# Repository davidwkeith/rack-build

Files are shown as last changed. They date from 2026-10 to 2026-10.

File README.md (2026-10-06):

# rack-build — 3D-printed 19" rack panels

Three parametric OpenSCAD panels for a home 19" rack. Source files are in
`scad/`; the printable STLs are attached to each
[release](https://github.com/davidwkeith/rack-build/releases) rather than
kept in the repo. Printers: 2x Prusa i3 MK3S (250x210 mm bed).

**Test-first, every panel:** print the piece with a snap-fit or clip mechanism
first (right half of the 1U, column 1 of the 2U, one keystone piece) and
dry-fit the hardware before committing to a full print run. Several
mechanisms here are first-pass designs validated by geometry checks, not by
an actual print — see the cautions under each section.

---

## Print settings (all three files)

- **Material:** PETG
- **Orientation:** every panel piece prints with its front plate face-down on
  the bed (the .scad files handle this rotation automatically — just slice
  the STL as exported, don't reorient it in the slicer)
- **Supports:** none, for any piece. Stops, bosses and rail ends rise at 45
  degrees from the wall they grow out of, and the only overhangs left in
  the exported STLs are short bridges (12mm inside the Hue push-rod pier,
  16mm under the Pi sled, a 48mm strip of floor over the PoE window) and
  the tops of horizontal screw holes and pegs. A slicer's automatic
  supports will still build towers under every one of those holes, so
  leave supports switched off. This comes from measuring the STLs, not
  from a finished print.
- **Layer height / infill:** no hard requirement from the design; 0.2mm /
  15-20% infill is a reasonable default. Parts with threads cut directly
  into the plastic (standoffs, bosses) will hold a self-tapping screw better
  with higher infill in that specific region if your slicer supports it.

## Installation

To print the panels as published, download the STLs from the latest
[release](https://github.com/davidwkeith/rack-build/releases); nothing needs
installing. To change the designs or export the STLs yourself, you need
[OpenSCAD](https://openscad.org) and this repository.

On macOS, install the OpenSCAD development snapshot with
[Homebrew](https://brew.sh) (the release workflow builds with the
`openscad/openscad:dev` image, so the snapshot is the version to match):

```sh
brew install --cask openscad@snapshot
```

The cask doesn't put `openscad` on your PATH, which `build.sh` expects. Link
it:

```sh
ln -s /Applications/OpenSCAD.app/Contents/MacOS/OpenSCAD /usr/local/bin/openscad
```

(use `/opt/homebrew/bin` instead of `/usr/local/bin` on Apple Silicon).

Then clone the repository:

```sh
git clone https://github.com/davidwkeith/rack-build.git
cd rack-build
```

## Building

STLs are only generated by release builds: pushing a `v*` tag runs
[the release workflow](.github/workflows/release.yml), which exports every
piece and attaches the STLs to a GitHub release. To export them yourself
into `stl/` (ignored by git; needs `openscad` on your PATH, see
[Installation](#installation)):

```sh
./build.sh release
```

The preview images in this README are committed. After changing a source
file, re-render them with:

```sh
./build.sh
```

---

## Hardware shopping list (consolidated)

| Qty | Item | Used for |
|---|---|---|
| 18x | M3 x 8mm socket-head cap screw | Panel joints: 3 (1U Hue/Pi) + 12 (2U audio) + 3 (keystone) |
| 18x | M3 hex nut | Panel joints (nut traps) |
| 12x | 1.75mm filament offcuts, ~10mm long | Joint alignment dowels: 2 + 8 + 2 |
| 8x | M2.5 self-tapping screw | Raspberry Pi 5 to sled standoffs (4 per sled); not needed where a HAT's own standoffs do the job |
| 2x | M3 self-tapping screw | PoE++ bracket standoffs |
| 4x | M3 x 6mm pan-head self-tapping screw | Kinter MA170 tab mounting (2 per amp; 6x with a third zone). The tabs are 2mm, so the longest safe screw is 7mm; 6mm is the standard size that fits |
| 12x | M6 cage nut + screw | Rack ears, 4 per panel (the 2U has 8 holes; 4 is enough) |

Every joint is two 6mm flanges with a 3mm head recess on one side and a
2.8mm nut trap on the other, so an 8mm bolt ends inside the nut. A 10mm
bolt works too; it stands 1mm proud of the flange, clear of every device.

---

## 1. 1U — Hue Bridge + PoE++ injector + 2x Raspberry Pi 5

<picture>
  <source media="(prefers-color-scheme: dark)" srcset="images/rack-1u-hue-pi-dark.png">
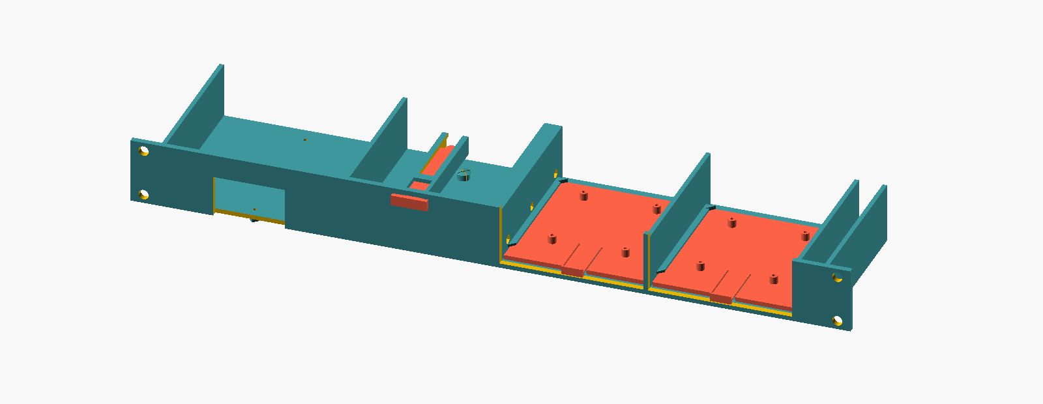
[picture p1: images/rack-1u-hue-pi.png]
1U shelf seen from the front: Hue bay with its push-rod on the left, two Raspberry Pi sleds on the right
  
</picture>

*Assembled, with the separately printed sleds, push-rod and pin in red.*

**Source:** `scad/rack-1u-hue-pi.scad`
**Pieces:** `rack-1u-left.stl`, `rack-1u-right.stl`, `rack-1u-sled.stl` (**print this one twice** — one per Pi), `rack-1u-pin.stl`, `rack-1u-rod.stl`

- **Left piece:** Philips Hue Bridge (model 3241312018) — front push-rod
  reaches the top sync button, two split snap-fit posts engage the Bridge's
  own keyhole + oval mounting slots. The UniFi PoE++ Adapter (60W) clips
  onto 2 printed standoffs on the floor's underside (92.80mm hole spacing,
  front-to-back) and hangs below the shelf; a 48x28mm front window keeps
  both port labels readable.
- **Right piece:** two Raspberry Pi 5 + PoE HAT sleds — one Home Assistant,
  one TBD. Each slides in from the front and latches via a flexing tongue
  riding a ratchet tooth, rather than lifting out from above (earthquake
  country — a Pi swap never needs the panel pulled from the rack). USB
  ports face front. The bays are sized for a Pi 5 under a
  [52Pi P30 PoE+ HAT](https://wiki.52pi.com/index.php?title=EP-0238), a
  ~30mm stack; that is tall enough that the bays are open at the top of the
  front plate rather than framed.

**Joint:** 3x M3 bolt + nut, 2x filament dowel, per half-to-half seam (one
seam total on this panel) = **3 bolts, 3 nuts, 2 dowels**.

**Assembly:**
1. Dry-fit one Pi sled into the right piece before printing a second — check
   the latch clicks in and lifting the pull lip releases it cleanly.
2. Bolt the two halves together while both are still empty: the bolt heads
   sit in the Hue bay and the nuts in the first Pi bay, and the Hue covers
   two of the three heads once it's in. Heads go in from the left piece's
   face, nuts tighten on the right piece's face. Seat the filament dowels
   first so the faces can't shift while you torque the bolts.
3. Push the Hue Bridge down into its left-piece pocket until the snap posts
   click; thread the push-rod and pin into the button-pusher channel from
   the front.
4. Screw the PoE++ adapter onto its 2 underside standoffs (M3 self-tap).
   **Check there's genuinely empty space in the rack slot directly below**
   — the adapter hangs ~31mm below the shelf floor.
5. Screw each Pi 5 onto its sled (4x M2.5 each, 8x total), USB/Ethernet
   toward the pull lip. If the HAT's standoffs have threaded studs, run
   those through the board into the sled's standoffs in place of the
   screws. Then slide both sleds into the right piece from the front until
   they latch. To pull one, lift the lip under the Pi's ports
   and draw the sled out by it.
6. Mount in the rack with M6 cage nuts.

**Open items** (all need the real hardware, not more modelling):
- **Needs calipers:** the Hue snap-post offsets are a photo estimate — if a
  post doesn't land in its slot, that's the first thing to re-check
  (`khole_dy` / `oval_dy`).
- **Needs a test fit:** the Pi + HAT height is 52Pi's published ~30mm, not
  a measurement. The model leaves it 2.7mm under the top of the 1U; set
  `pi_stack_h` if yours differs.
- **Needs a test print:** the Pi sled latch (flexing tongue + ratchet tooth)
  clears every interference check in the model but is untested as a
  physical mechanism. `ramp_h` in the .scad file is the knob to back off
  if the tooth grips too hard to release by hand.

---

## 2. 2U — Audio stacks (up to 3 AirPlay zones)

<picture>
  <source media="(prefers-color-scheme: dark)" srcset="images/rack-2u-audio-stacks-dark.png">
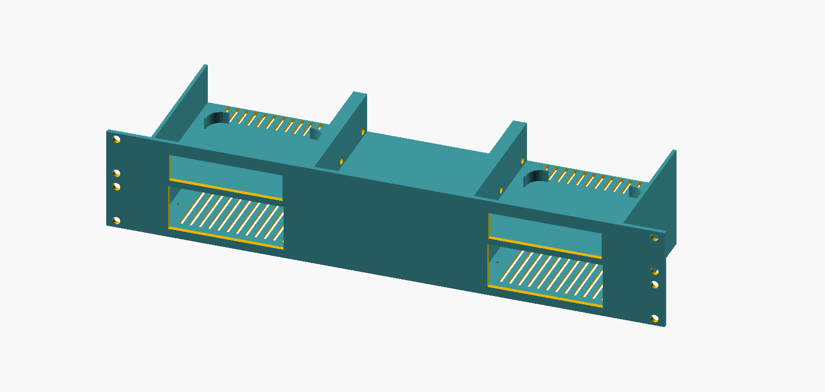
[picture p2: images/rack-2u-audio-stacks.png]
2U panel seen from the front: three bolted columns, the outer two with an AirPort window above an amp window
  
</picture>

**Source:** `scad/rack-2u-audio-stacks.scad`
**Pieces:** `audio-1.stl`, `audio-2.stl`, `audio-3.stl` (or `audio-2-stack.stl` in place of `audio-2.stl` for a third zone)

Three bolt-together columns. Each stack pairs one AirPort Express (upper U)
directly above one Kinter MA170 amp (lower U), one stack per AirPlay zone.

- **Columns 1 & 3 (zones 1 and 2):** AirPort front-flush (face against the plate, behind a full-face
  window for the status light) and two curved holders hugging its rear
  corners so it can't slide back; Kinter behind a 100 x 40mm window its knobs poke
  through (they stand 20mm proud of the front plate, for finger adjustment),
  with two printed screw bosses under the amp's factory mounting tabs.
  Front-to-back vent slots under the amp and in the upper floor behind the
  AirPort let its heat rise out of the stack. The amp
  floor sits 4mm up so those bosses stay inside the panel, and the AirPort
  floor sits 1mm above the amp rather than on the U line.
- **Column 2:** blank — the same floors and joints with no windows, holders
  or bosses. For a third zone, print `audio-2-stack.stl` as the middle
  piece instead: it is the same stack as columns 1 and 3 and bolts up
  identically.

**Joint:** 2 seams (col 1-2, col 2-3), each 6x M3 bolt + nut (3 Y-positions x
2 Z-levels, one level per U) + 4x filament dowel = **12 bolts, 12 nuts, 8
dowels** total across both seams.

**Assembly:**
1. Print column 1 first and dry-fit an amp and an AirPort in it before
   printing the rest.
2. Bolt the empty columns together in order (1-2, then 2-3), dowels first,
   same as the 1U panel. The bolt heads and nuts sit inside the bays, so
   this has to happen before the amps go in.
3. Slide each Kinter MA170 into its lower U from the rear until its face
   meets the front plate, and screw it to the floor bosses through the
   amp's factory tabs. The two driver holes in the upper floor sit straight
   above the tab screws: lower each screw through on the driver.
4. Slide each AirPort Express into its upper U from the rear until its face
   meets the front plate and the two curved rear holders cup its back corners. The driver holes stay clear either side of it, so
   an amp can come out without disturbing the AirPort.
5. Mount with M6 cage nuts — these columns carry protruding ear tabs that
   reach the rack's true 482.6mm width (the 3 columns' own content only
   spans 408mm).

**Open items:**
- **Tab screws:** the amp's tabs are 2mm, so the blind pilots (1mm skin
  under them) take a screw up to 7mm; M3 x 6mm gives about 4mm of grip.
- **Needs a test fit:** the amp bay is built from caliper measurements of
  one MA170 (103 x 70 x 43mm case, 124.5mm across the tabs, slots 113mm
  apart and 30-42mm behind the face) but hasn't been printed. Fit an amp
  to column 1 before printing the rest.

---

## 3. 1U — 24-port keystone patch panel

<picture>
  <source media="(prefers-color-scheme: dark)" srcset="images/rack-1u-keystone-panel-dark.png">
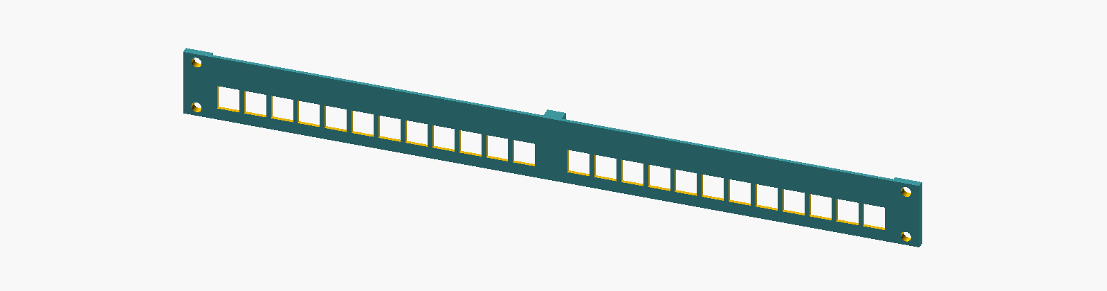
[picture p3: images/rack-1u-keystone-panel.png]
1U keystone panel seen from the front: two bolted halves with twelve square cutouts each
  
</picture>

**Source:** `scad/rack-1u-keystone-panel.scad`
**Pieces:** `keystone-left.stl`, `keystone-right.stl` (12 ports each)

Standard 14.5 x 16mm keystone cutouts, industry-standard across brands.
Panel's thinned to 2.5mm specifically so keystone clips can actually engage
(the rest of this rack's panels are 4mm — too thick for most keystone
jacks' spring clips to reach). Ports sit low in the panel, leaving ~20mm of
clear space above each one for a label.

**Joint:** 3x M3 bolt + nut, 2x filament dowel = **3 bolts, 3 nuts, 2
dowels**.

**Assembly:**
1. **Print one piece and test a single keystone jack before printing both**
   — clip tolerance varies enough by brand/model that this is worth
   confirming. If jacks won't seat, thin the panel further; if they're
   loose, that's likely fine (the clip still does the retaining).
2. Bolt the two pieces together same as the other panels (heads from the
   left piece, nuts on the right, dowels first).
3. Snap jacks in from the rear, terminated or not — they self-retain, no
   bracket needed behind the panel.
4. Mount with M6 cage nuts.

---

## Also in the rack

Two things in the rack aren't these panels:

- **Router:** the UCG Fiber and its power supply sit in the
  [UCG Fiber + PSU 19 inch modular rack mount](https://www.printables.com/model/1359874-ucg-fiber-psu-19-inch-modular-rack-mount)
  by [Maurício Pessoa](https://www.printables.com/@Mauker) on Printables,
  printed as published.
- **Switch:** a Ubiquiti EdgeSwitch 24 (ES-24-250W), a 1U unit that mounts
  on its own rack ears with no printed parts.

---

## Superseded / not included

- `rack-1u-kinter-amps.scad` — standalone single-amp panel, replaced by the
  2U audio stacks (each amp now pairs with its own AirPort Express instead).
- An earlier "keyhole" cable-management panel design was replaced entirely
  by the keystone panel above — no files from that version exist.

Both are left out of this collection since they're not part of the current
build.

---

## Credits

All geometry here is original, but two ideas came from other people's
models on Printables:

- The Hue button pusher follows RobinUit's "button pusher" (model 480200).
- The front-loading Pi sleds nod to JaredC01's "1U Rackmount Cluster"
  (model 285853).

The Hue snap-post spacing was cross-checked against vladimir.aubrecht's
remix (model 125408) of Luther2k's Hue rack mount.

## License

[ISC](LICENSE) © [David W. Keith](https://dwk.io)

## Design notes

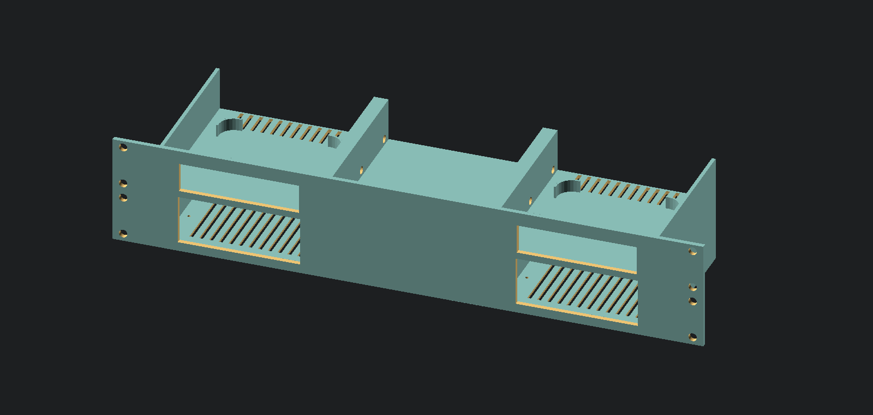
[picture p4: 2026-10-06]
images/rack-2u-audio-stacks-dark.png

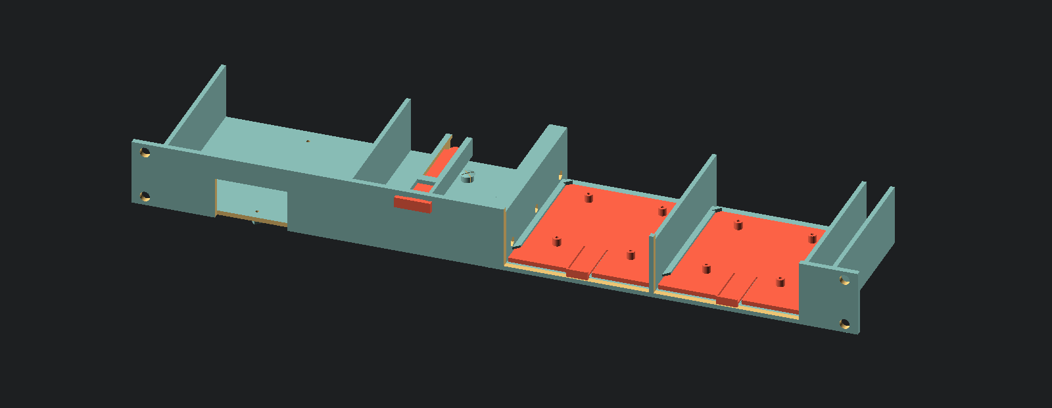
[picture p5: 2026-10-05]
images/rack-1u-hue-pi-dark.png

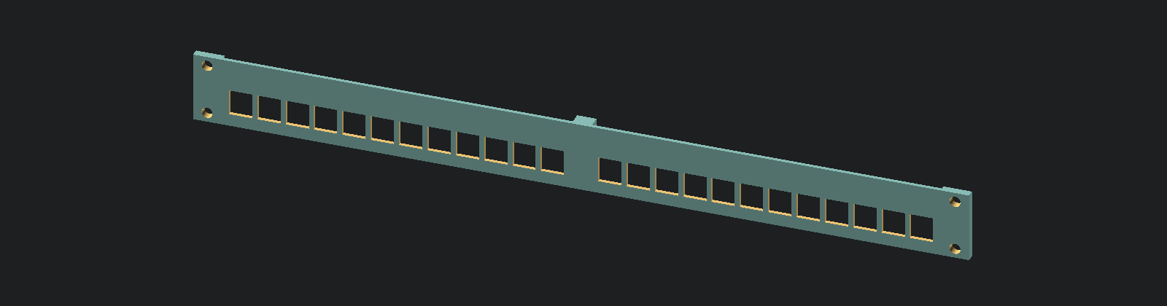
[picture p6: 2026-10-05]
images/rack-1u-keystone-panel-dark.png

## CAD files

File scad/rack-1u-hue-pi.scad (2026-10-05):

// 1U 19" rack mount, two halves bolted at the centre.
//   Left half : 1x Hue Bridge v2 + 1x Ubiquiti PoE++ Adapter (60W, U-POE++)
//   Right half: 2x Home Assistant Raspberry Pi 5 + PoE HAT, each on a removable sled (below)
// The Hue sits rear-flush (ports at the back) and gets a front push-rod button pusher (see its
// own section below) -- no LED light pipes, the unit's status LEDs are too dim to be worth
// routing. The PoE++ injector hangs from standoffs under the floor -- its Ethernet ports face
// the rack front through a window, AC cord exits to the rear.
// Print each half front-plate-down (print_orient = true), no supports. PETG, brim helps.
// Half is 241.3 mm wide; MK3S bed is 250 x 210.
// Model coordinates: X across, Y front(0)->rear, Z up. Floor bottom at Z=0.

/* [Part] */
part = "both"; // [both, assembly, left, right, pin, rod, sled]

/* [Rack (EIA-310)] */
rack_w      = 482.6;
ear_hole_x  = 465.1;   // hole centre-to-centre
ear_hole_dz = 31.75;   // 1U hole pair spacing
ear_hole_d  = 6.8;     // M6 cage-nut clearance
panel_h     = 43.66;   // 1U minus clearance
body_margin = 17.5;    // keep body inside the rails

/* [Shelf] */
plate_t     = 4;
floor_t     = 3;
wall_t      = 3;
wall_h      = 37;      // above floor -- tall enough to contain the PoE injector (34 mm) + a lip
flange_t    = 6;       // joint flange per half
shelf_depth = 116;     // includes plate_t -- deepened for the 106 mm-long PoE++ injector

/* [Devices: width(X) x depth(Y) x height(Z)] */
hue_dims = [91, 91, 26];     // Philips spec: ~90.6 x 90.9 x 26 mm
clr      = 1.0;              // total side clearance, all devices
hue_stop = 0.5;               // gap between Hue front and its stop wall
stop_wall_h = 25;             // front-registration rib height for Hue (capped by the room in
                               // front of it) -- stays low so it doesn't block the Hue pusher rod
hue_stop_dx = 28;             // the two stop ribs sit this far either side of the Hue's centre

/* [PoE++ mounting bracket (screws to the shelf UNDERSIDE; adapter clips onto the bracket's
   own sliders and hangs below the shelf -- it is no longer in a floor pocket) ] */
// Only 2 real screw holes -- the large countersunk pair, 92.80 mm apart centre-to-centre
// (direct caliper reading between the holes themselves, not a photo-scale estimate). The
// small holes next to the cleat aren't mounting points at all: they're part of how the
// adapter LATCHES onto the cleat, not how the bracket attaches to whatever it's screwed to.
// Hole diameter is still a photo estimate -- confirm before printing.
// Orientation: in normal use the bracket mounts to a WALL with Ethernet at the top, power
// cord at the bottom -- so the two holes sit along the Ethernet-to-power axis. That's the
// same axis as the adapter's own front(Ethernet)-to-rear(power) run through this rack, so
// the holes go along Y (front-to-back), not X, with the front one nearer the window above.
// CAUTION: the bracket is a thin plate, but the clipped-on adapter is ~31 mm thick in this
// orientation (measured; spec sheet says 34) and hangs straight down from the shelf floor --
// that will very likely intrude
// into whatever occupies the 1U slot directly below (e.g. the Kinter amp panel) unless a
// clear 1U gap is left there. Check real rack clearance before committing to this mount.
bracket_hole_dy = 46.4;    // half-spacing: 2 holes, 92.80 mm apart, same X (front/rear of bracket_cy)
bracket_cx = 162;          bracket_cy = shelf_depth / 2;   // centre of the hole pattern, in the
                                                             // left half's spare bay (local u)
                                                             // -- pick your own spot if this is wrong
bracket_pilot_d = 2.5;     // pilot hole for a self-tapping M3
bracket_boss_d  = 7;       bracket_boss_h = 4;   // printed standoff, hangs below the floor
// Connector end measured directly with calipers: 63.94 mm wide, ~31.2 mm tall (vs. 63 x 34 mm
// from Ubiquiti's spec sheet -- close on width, spec runs a bit tall, probably measured over a
// foot or lip calipers didn't catch). Widened from a plain cable slot to a real window so the
// two port labels (data / PoE++) printed above the jacks stay readable, not just cable access.
poe_pass_w = 48;  poe_pass_h = 28;  poe_pass_drop = 6;   // front window, open at the plate's
                                                           // bottom edge since the adapter hangs
                                                           // below rather than sitting in a pocket

/* [Home Assistant Pi sled -- front-slide, latching, swappable tray]
   Earthquake country, and the Pis are the part most likely to get swapped -- so the sled now
   slides in and out through the FRONT on a pair of rails, with a spring latch, instead of
   lifting out from above. A vertical lift would need clearance above this 1U that may not
   exist once the rack is populated; a front slide never requires pulling the panel. Concept
   nods to JaredC01's "1U Rackmount Cluster" (Printables 285853) but the mechanism is
   original -- theirs locks 5 sleds together with an all-thread rod through interlocking
   modules, built for a 5-bay PoE+OLED cluster; this is one bay with a simple channel + latch.
   UNTESTED PRINT-AND-FIT, like every other snap/latch in this file: dry-fit the rail
   clearance and latch spring force before committing to a full print. */
sled_dims = [95, 100, 3];        // W x D x plate thickness
sled_clr  = 1.5;                 // side clearance, bay vs sled
sled_corner = 6;                 // 45-degree cut on the sled's rear corners (see the rear stops)
sled_front_gap = 2;              // sled's front edge, FULLY INSERTED, to the plate's inner face
sled_overtravel = 1;             // how far past its latched position the sled can be pushed before
                                 // it meets the rear stop -- without this the catch bar has only
                                 // latch_clr to drop behind the tooth, less than print tolerance

/* [Pi sled rails + latch] */
rail_t = 1.6;      rail_depth = 4;     // retention lip: thickness, reach in from each side wall
rail_z0 = 0.3;                          // lip floats this far above the sled plate's top face
rail_start = 16;                        // lip begins this far back from the front opening, so
                                          // the sled's leading edge is already past the window
                                          // before the rails start gripping it
latch_w = 14;       latch_len = 30;     // cantilever tongue cut into the sled plate: width, length
latch_slit = 1;                         // slit width freeing the tongue to flex
latch_travel = 8;                       // rear edge of the tongue's catch bar, from the sled's
                                          // front edge. The bar is the only part of the sled left
                                          // full-thickness along the tooth's track -- the rest of
                                          // that track is relieved underneath (see pi_sled()) so
                                          // the sled can pass over the raised tooth at all
latch_catch = 3;                        // catch bar length; the tooth's sheer face lands just
                                          // in front of it once the sled is fully inserted
latch_clr = 0.3;                        // tooth-to-sled clearance, vertical and fore/aft
lip_ridge = [1.5, 2.5];                 // finger ridge at the pull lip's tip: thickness, height
ramp_len = 6;        ramp_h = 1.2;      // ratchet tooth: gentle rise over ramp_len, then an
                                          // immediate sheer drop -- easy to slide in over, caught
                                          // behind the drop when pulled back out
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

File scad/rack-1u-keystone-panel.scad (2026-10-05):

// 1U 19" keystone patch panel, 24 ports (12 per piece), 2-piece bolt-together -- same EIA-310
// ears, M3 + nut-trap + filament-dowel joint, and front-plate-down print orientation as the
// other panels in this rack.
// Keystone cutout is a true industry standard, confirmed across multiple manufacturers
// (TrueCable, IDEAL, Digi-Key mechanical drawings): 14.5 mm wide x 16.0 mm tall, relying on
// the jack's own integrated spring clip + fulcrum to self-retain -- no bracket needed behind
// the panel. That clip has limited reach, though: one DIYer's mechanical-drawing check found
// a jack "barely tolerate[d]" a 2.0 mm panel and wouldn't take anything thicker. The rest of
// this rack's front plates are 4 mm; this one is thinned to 2.5 mm specifically so the clips
// have a real chance of engaging. PRINT A SINGLE TEST CUTOUT with your actual jacks before
// committing to a full 24-port print -- clip tolerance varies enough by brand that this is
// worth confirming, not assuming.

/* [Part] */
part = "both"; // [both, left, right]
print_orient = true;   // lie the panel flat instead of standing it on its thin edge -- same
                        // tip-over and horizontal-hole-printing reasons as the other panels

/* [Rack (EIA-310)] */
rack_w      = 482.6;
ear_hole_x  = 465.1;
ear_hole_dz = 31.75;
ear_hole_d  = 6.8;
panel_h     = 43.66;   // 1U minus clearance, matches the other panels
body_margin = 17.5;

/* [Plate] */
plate_t = 2.5;        // thinned for keystone clip engagement -- see header note
flange_depth = 10;    // joint flange reaches this far BEHIND the plate (there's no shelf/floor
                        // here to borrow overlap thickness from like the other panels, so each
                        // piece grows its own small flange block at the shared edge instead)

/* [Keystone cutouts] */
n_per_piece = 12;                 // 24 total across both pieces
keystone_w = 14.5;  keystone_h = 16.0;   // industry-standard cutout, confirmed across brands
keystone_z = 15.83;               // moved down from centred (21.83) -- leaves ~20 mm of clear
                                    // panel above each port for a label, ~8 mm below

/* [Ear reinforcement] */
// The panel's thinned to 2.5 mm for the keystone clips, but a rack screw clamping down on
// only 2.5 mm of material right at the ear is asking for a cracked or stripped hole. Each ear
// gets a local pad bringing it back up to a sturdier 5 mm, running the full panel height.
ear_pad_w = 18;  ear_pad_t = 5;

/* [Joint (M3), same hardware as the other panels] */
bolt_d = 3.4;  head_d = 6.4;  head_depth = 3;
nut_af = 5.7;  nut_depth = 2.8;
dowel_d = 2.0; dowel_depth = 5;
flange_t = 6;  outer_t = 3;

half_w   = rack_w / 2;

// Port span has to clear BOTH ends now: the joint flange on one side, the ear pad on the
// other -- and which side is which flips between L and R (neither piece is mirrored, so
// "outer edge" is local X=0 for the left piece but local X=half_w for the right piece).
// gap is a buffer beyond each feature's own footprint; ear_half is the pad's reach from its
// own centre (ear_u), computed the same way per side in half_local() below.
port_gap  = 3;
// The ear itself sits (rack_w-ear_hole_x)/2 = 8.75 mm in from the piece's outer edge -- that
// inset has to be added, not just the pad's own half-width, or the first/last port overlaps
// the pad by about that same 8.75 mm (caught by checking the actual cutout, not just that
// port_gap looked reasonable on paper).
ear_half  = (rack_w - ear_hole_x) / 2 + ear_pad_w / 2 + port_gap;
flange_lo = flange_t + port_gap;
port_span = half_w - ear_half - flange_lo;
pitch     = port_span / n_per_piece;
echo(str("keystone pitch = ", pitch, " mm  (", keystone_w, " mm port, ",
         pitch - keystone_w, " mm gap between adjacent ports)"));
if (pitch < keystone_w) echo("WARNING: pitch is narrower than the port itself -- ports would overlap");

bolt_z  = [panel_h * 0.22, panel_h * 0.5, panel_h * 0.78];   // 3 bolts, spread over the height
dowel_z = [panel_h * 0.36, panel_h * 0.64];

// cylinder along X, from x=u for length h -- bolts/dowels run this way, across the seam
module xcyl(u, y, z, d, h, fn = 32) {
  translate([u, y, z]) rotate([0, 90, 0]) cylinder(d = d, h = h, $fn = fn);
}

module keystone(cx) {
  translate([cx - keystone_w / 2, -1, keystone_z - keystone_h / 2])
    cube([keystone_w, plate_t + 2, keystone_h]);
}

module half_local(side) {
  // The panel is only plate_t thick -- not enough material on its own for a bolt + nut-trap
  // joint, so each piece grows a flange_depth-deep block at the shared edge only (same M3 +
  // nut-trap + filament-dowel hardware as the other panels in this rack).
  fx0 = (side == "L") ? half_w - flange_t : 0;
  // Neither piece is mirrored -- each is built directly in its final position, so "near the
  // outer rack edge" is local X=0 for the left piece but local X=half_w for the right piece.
  // The flange (fx0, above) already accounts for this; the ear needs to as well.
  ear_u = (side == "L") ? (rack_w - ear_hole_x) / 2 : half_w - (rack_w - ear_hole_x) / 2;
  difference() {
    union() {
      cube([half_w, plate_t, panel_h]);
      translate([fx0, 0, 0]) cube([flange_t, flange_depth, panel_h]);
      // Ear reinforcement pad, see header note. One full-height strip from the piece's outer
      // edge to ear_pad_w/2 past the holes -- square pads centred on each hole would overhang
      // the panel's top, bottom and outer edges and foul the neighbouring rack units.
      ear_pad_x0 = (side == "L") ? 0 : ear_u - ear_pad_w / 2;
      translate([ear_pad_x0, 0, 0])
        cube([(rack_w - ear_hole_x) / 2 + ear_pad_w / 2, ear_pad_t, panel_h]);
    }
    for (dz = [-1, 1])
      translate([ear_u, -0.1, panel_h / 2 + dz * ear_hole_dz / 2])
        rotate([-90, 0, 0]) cylinder(d = ear_hole_d, h = ear_pad_t + 0.2, $fn = 40);
    // Start from whichever end has the EAR on this piece (ear_half clearance); the other end
    // clears the flange instead (flange_lo). Same swap as fx0/ear_u above.
    port_start = (side == "L") ? ear_half : flange_lo;
    for (i = [0 : n_per_piece - 1])
      keystone(port_start + pitch / 2 + i * pitch);
    // Bolts run ACROSS the seam (X), not into the panel (Y) -- each piece's flange is only
    // flange_t wide, so a bolt has to pass all the way through one piece's flange, across the
    // seam, and partway into the other piece's flange to reach the nut on the far side. Which
    // end is "outer" (head/nut) vs "seam-facing" flips with fx0/ear_u above: for L the flange
    // sits at the high-X end of the piece (outer face = low X, fx0 side); for R it sits at the
    // low-X end (outer face = high X, fx0+flange_t side).
    jy = flange_depth / 2;
    for (z = bolt_z) {
      xcyl(fx0 - 0.1, jy, z, bolt_d, flange_t + 0.2);
      if (side == "L") xcyl(fx0 - 0.1, jy, z, head_d, head_depth + 0.1);
      else              xcyl(fx0 + flange_t - nut_depth, jy, z, nut_af / cos(30), nut_depth + 0.1, 6);
    }
    // Dowels also cross the seam, same as the bolts -- a dowel pin spans the full combined
    // flange_t + flange_t once assembled.
    for (z = dowel_z) xcyl(fx0 - 0.1, jy, z, dowel_d, flange_t + 0.2, 24);
  }
}

module left_half()  { half_local("L"); }
module right_half() { translate([half_w, 0, 0]) half_local("R"); }

module oriented() {
  if (print_orient) translate([0, panel_h, 0]) rotate([90, 0, 0]) children();
  else children();
}

gap = (part == "both") ? 10 : 0;
if (part == "left"  || part == "both") oriented() left_half();
if (part == "right" || part == "both") translate([gap, 0, 0]) oriented() right_half();

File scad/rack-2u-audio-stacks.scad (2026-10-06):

// 2U 19" rack panel, THREE bolt-together columns (one per bed-sized piece). Each column is
// one AirPort Express (upper U) directly above one Kinter MA170 amp (lower U) -- a stack per
// audio zone. Supersedes the old 1U left half (2x AirPort) and the standalone Kinter panel
// (which only fit 2 amps): this holds up to 3 zones, with the middle column blank by default.
// Hue + the PoE++ injector are NOT here -- they stay on their own panel (rack-1u-hue-pi.scad).
//
// Column width is set by the WIDER device (the Kinter amp); the AirPort, being narrower,
// sits centred in the same column. Each column is its own piece (three Kinter amps side by
// side would not fit one bed-sized piece, same constraint as before).
// Print front-plate-down (print_orient), same reasoning as the other panels: the control-panel
// and AirPort windows are too wide to bridge printed any other way.

/* [Part] */
part = "all"; // [all, 1, 2, 2-stack, 3]
print_orient = true;

/* [Rack (EIA-310)] */
rack_w      = 482.6;
U           = 44.45;          // one rack unit
panel_h     = 2 * U - 0.79;   // 2U minus the same clearance used on the 1U panels
ear_hole_x  = 465.1;
ear_hole_dz = 31.75;          // hole-pair spacing within one U
ear_hole_d  = 6.8;

/* [Shelf] */
plate_t = 4;
wall_t  = 3;
flange_t = 6;   outer_t = 3;        // joint walls run the FULL 2U height on this design
shelf_depth = 130;

/* [Kinter MA170 -- lower U. Calipered off a real amp. Its dimension diagram's 4-7/8" turned
   out to be the width across the mounting tabs and its 4-5/8" the depth over knobs and
   terminals; the case itself is a good deal smaller than either. ] */
amp_dims  = [103, 70, 43];     // case only: width, depth (no knobs or terminals), height
amp_tab_w = 124.5;             // width across the two mounting tabs, tip to tip
amp_clr   = 1.5;
amp_floor_t = 2;
amp_headroom = 1;              // between the amp's top and the upper floor
amp_front_gap = 3;
// Front window: the knobs stand 20 mm proud of the front plate (27 mm from the case face,
// through the 3 mm gap and 4 mm plate), so they reach out into the rack for finger adjustment.
// The window is sized to the knob cluster, centred on the case face.
amp_win_w = 100;  amp_win_h = 40;
// Tab slots are 3.5 mm wide x 12 mm long, 113 mm apart centre to centre, and run from 30 to
// 42 mm behind the case's front face. The tabs sit flat on the floor (the amp has no feet).
amp_tab_dx = 113;                 // slot centre to slot centre
amp_tab_y  = 36;                  // slot centre, behind the case's front face
amp_tab_pilot_d = 2.5;            // self-tap pilot, in the floor and the boss beneath it
amp_pilot_skin  = 1;              // pilot is BLIND: this much boss is left under it, so a screw
                                  // can never come out of the panel's underside. Longest screw
                                  // that is safe = tab thickness + (amp_floor_t + amp_boss_h
                                  // - amp_pilot_skin) = tab + 5 mm; aim for tab + 4..5 mm.
amp_boss_h = 4;                   // boss under each tab screw, so it has more than the thin
                                  // floor to bite into. The lower floor is raised by this much
                                  // so the bosses stay inside the panel's own 2U envelope.
vent_w = 3;                       // slots run front-to-back so a 3 mm bridge is all they cost
vent_pitch = 8;  vent_span = 90;  // across the amp's width, clear of the tab bosses and driver holes
amp_vent_y   = [10, 70];          // (y from the plate's back face) lower floor, under the amp: air in from the open underside
ap_vent_y    = [102, 124];        // upper floor, behind the AirPort (it ends at y=102, front-flush; the rear holders' lip is just behind it):
                                  // the amp's heat rises past the AirPort bay's open top instead
                                  // of being trapped under it
amp_tab_access_d = 8;             // driver holes through the UPPER floor, straight above the tab
                                  // screws -- the only vertical way in once the amp is in place

/* [AirPort Express 2nd gen -- upper U] */
ap_dims  = [98, 98, 23];
ap_clr   = 1.0;
ap_floor_t = 3;
ap_win_w = 98;  ap_win_h = 24;
ap_corner_r = 12;               // AirPort's plan-view corner radius (the holders trace it)
ap_holder_t = 1.6;              // curved holder wall thickness
ap_holder_h = 10;               // ... and height above the upper floor
ap_holder_len = 16;             // reach of each holder from the rear corner, along the rear and the side

/* [Joint hardware -- M3 + filament dowels, same as the other panels, now at two Z levels] */
bolt_d = 3.4;  head_d = 6.4;  head_depth = 3;
nut_af = 5.7;  nut_depth = 2.8;
dowel_d = 2.0; dowel_depth = 5;

z_amp = amp_boss_h;         // underside of the lower (amp) floor
z_ap  = z_amp + amp_floor_t + amp_dims[2] + amp_headroom;   // underside of the upper (AirPort) floor

amp_pw = amp_tab_w + amp_clr;         // the tabs, not the case, set the bay width
ap_pw  = ap_dims[0] + ap_clr;
col_w  = amp_pw;                       // the wider device sets the column width
ap_x_margin = (col_w - ap_pw) / 2;     // AirPort is centred within the column

P1_w = outer_t + col_w + flange_t;
P2_w = flange_t + col_w + flange_t;
P3_w = flange_t + col_w + outer_t;
echo(str("column widths: 1=", P1_w, " 2=", P2_w, " 3=", P3_w,
         "  (3 cols use ", P1_w+P2_w+P3_w, " of ", rack_w, " mm rack width)"));

bolt_y  = [plate_t + 14, shelf_depth / 2, shelf_depth - 14];
bolt_z_levels  = [14, U + 14];
dowel_y = [plate_t + 28, shelf_depth - 28];
dowel_z_levels = [22, U + 22];

module xcyl(u, y, z, d, h, fn = 32) {
  translate([u, y, z]) rotate([0, 90, 0]) cylinder(d = d, h = h, $fn = fn);
}

// Flange-local coordinates: x=0 is the SEAM face, x=flange_t the interior (device-facing) face.
// Head recesses and nut traps open onto the interior face so they stay reachable once two
// columns are butted together; dowel sockets open onto the seam. A right-hand flange gets
// these same cuts mirrored (see skeleton()).
module joint_cuts(side) {
  for (y = bolt_y) for (z = bolt_z_levels) {
    xcyl(-0.1, y, z, bolt_d, flange_t + 0.2);
    if (side == "head") xcyl(flange_t - head_depth, y, z, head_d, head_depth + 0.1);
    else                 xcyl(flange_t - nut_depth, y, z, nut_af / cos(30), nut_depth + 0.1, 6);
  }
  for (y = dowel_y) for (z = dowel_z_levels)
    xcyl(-0.1, y, z, dowel_d, dowel_depth + 0.1, 24);
}

// The 3 columns only span 406.5 of the rack's 482.6 mm -- ear holes placed relative to a
// column's own edge would float in mid-air, well short of the actual rack rails. Real ear
// TABS make up the difference: a plain plate_t-thick flange reaching from the column's outer
// edge out to the rack's true mounting-hole position, same panel_h height as the front plate.
ear_tab_w = (rack_w - (P1_w + P2_w + P3_w)) / 2;
inset = (rack_w - ear_hole_x) / 2;   // hole inset from the TRUE rack edge, both ends

module ear_tab(hole_at_left) {
  u = hole_at_left ? inset : ear_tab_w - inset;
  difference() {
    cube([ear_tab_w, plate_t, panel_h]);
    for (u_center = [U / 2, U + U / 2])          // one hole-pair per U
      for (dz = [-1, 1])
        translate([u, -0.1, u_center + dz * ear_hole_dz / 2])
          rotate([-90, 0, 0]) cylinder(d = ear_hole_d, h = plate_t + 0.2, $fn = 40);
  }
}

module skeleton(w, left_is_flange, left_side, right_is_flange, right_side) {
  difference() {
    union() {
      cube([w, plate_t, panel_h]);                                                 // front plate
      translate([0, plate_t, z_amp]) cube([w, shelf_depth - plate_t, amp_floor_t]);  // lower floor
      translate([0, plate_t, z_ap]) cube([w, shelf_depth - plate_t, ap_floor_t]);    // upper floor
      if (left_is_flange) translate([0, plate_t, 0]) cube([flange_t, shelf_depth - plate_t, panel_h]);
      else cube([outer_t, shelf_depth, panel_h]);
      if (right_is_flange) translate([w - flange_t, plate_t, 0]) cube([flange_t, shelf_depth - plate_t, panel_h]);
      else translate([w - outer_t, 0, 0]) cube([outer_t, shelf_depth, panel_h]);
    }
    if (left_is_flange) translate([0, plate_t, 0]) joint_cuts(left_side);
    if (right_is_flange) translate([w, plate_t, 0]) mirror([1, 0, 0]) joint_cuts(right_side);
  }
}
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

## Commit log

2026-10-05 feat: import parametric OpenSCAD rack panels
    Three 19" rack panels (1U Hue/PoE++/Pi, 2U audio stacks, 1U keystone)
    with OpenSCAD sources and exported STLs, licensed ISC.
    [audio-1.stl, audio-2.stl, audio-3.stl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]
2026-10-05 fix(audio-2u): open bolt recesses on the interior flange faces
    Head recesses and nut traps were cut into the seam faces, where they are
    buried once two columns butt together, and right-hand flanges had dowel
    sockets that stopped 1 mm short of the seam. Mirror the joint cuts for
    right-hand flanges and re-export the three columns.
    [audio-1.stl, audio-2.stl, audio-3.stl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]
2026-10-05 fix(keystone): keep ear pads inside the 1U envelope
    The square ear pads overhung the panel by 3 mm top and bottom and
    0.25 mm at each outer edge, which would foul adjacent rack units.
    Replace them with one full-height strip per ear and re-export.
    [keystone-left.stl, keystone-right.stl, rack-1u-keystone-panel.scad]
2026-10-05 fix(pi-sled): make the latch clear the tooth and face USB forward
    The sled's underside was flat, so it collided with the shelf's raised
    ratchet tooth along its whole travel and when fully home, and the latch
    tongue was joined at both ends so it could not flex. Open the tongue at
    the front edge and relieve the tooth's track underneath, leaving one
    full-thickness catch bar that drops behind the tooth.
    The standoffs also sat 3.5 mm from the front edge, which matches the
    board's SD-card end rather than the USB/Ethernet end the sled is meant
    to present. Move them to 23.5 mm.
    Drop the unused AirPort and PoE-pocket code left in this file; left and
    right half geometry is unchanged.
    Co-Authored-By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
    [rack-1u-airport-hue-pi.scad, rack-1u-sled.stl]
2026-10-05 docs: correct hardware counts, assembly order and open items
    Joint hardware totals 18 bolts and 12 dowels, not 23 and ~20, and the
    bolts need to be 8 mm to stay clear of the amp bays. Both shelf panels
    have to be bolted together before devices go in, and keystone jacks
    load from the rear. Add build, credits and license sections.
2026-10-05 build: re-export remaining STLs with build.sh
    Same geometry, re-tessellated by the current OpenSCAD so the committed
    files match what the build script produces.
    [rack-1u-left.stl, rack-1u-pin.stl, rack-1u-right.stl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]
2026-10-05 refactor: rename 1U source to rack-1u-hue-pi.scad
    The panel no longer holds an AirPort Express.
    [rack-1u-hue-pi.scad, rack-2u-audio-stacks.scad]
2026-10-05 feat: add assembled views for previews
    Add an "assembly" part to the 1U Hue/Pi model that places the sleds,
    push-rod and pin where they sit in use. Fix the 2U "all" layout, which
    ignored piece 1's ear tab and drew column 2 overlapping it.
    [rack-1u-hue-pi.scad, rack-2u-audio-stacks.scad]
2026-10-05 fix(1u): resolve latch clearance and make every part print unsupported
    Sled: replace the pull-tab under the Pi with a pull lip that comes out
    through the front opening, lower the tooth to 1.2 mm, raise the
    standoffs to 5 mm and lengthen the tongue, so releasing the latch no
    longer depends on room under the board's connector pins. Allow 1 mm of
    over-travel so the catch bar has more than 0.3 mm to drop behind the
    tooth.
    Shelf: carry the Hue pusher pier down to the front plate, swap the Hue
    stop wall for two gusset ribs and the Pi rear stops for corner wedges
    (with matching cut corners on the sled), give the rail lips a 45-degree
    start, point the PoE bosses, and turn the snap-post slits diagon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
    [rack-1u-hue-pi.scad, rack-1u-left.stl, rack-1u-right.stl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]
2026-10-05 fix(audio-2u): give the amp tab screws driver access and keep bosses inside 2U
    Add driver holes through the upper floor straight above each tab screw,
    which were otherwise unreachable once the amp was in. Raise both floors
    4 mm so the screw bosses no longer hang below the panel, and shape the
    bosses, driver holes and AirPort dimple to print without supports.
    [audio-1.stl, audio-2.stl, audio-3.stl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]
2026-10-05 docs: add dark-mode previews, update open items, credit the router mount
    Render each preview in a dark scheme as well and switch the README to
    <picture> so GitHub serves the one matching the reader's theme. Replace
    the open items that the model changes resolved with what is left, which
    needs calipers or a test print. Link the Printables rack mount used for
    the UCG Fiber router.
2026-10-05 docs: credit the router mount's author
2026-10-05 docs: credit Maurício Pessoa for the router mount
    The previous commit attributed it to this repo's author. Link the
    author's own name to dwk.io instead.
2026-10-05 docs(audio-2u): flag that the amp bay rests on a doubtful reading
    Kinter's dimension diagram shows 4-7/8" across the case with the tabs
    outside it, not tab-to-tab as the model assumes. Say so in the source
    and the README until an amp has been measured.
    [rack-2u-audio-stacks.scad]
2026-10-05 fix(audio-2u): rebuild the amp bay from caliper measurements
    The Kinter MA170's case is 103 x 70 x 43 mm and 124.5 mm across its
    tabs, with slots 113 mm apart, not the 124 x 117 x 41 mm block the bay
    assumed. Size the bay to the tabs and the window to the case, move the
    tab screws, bosses and driver holes to the measured slots, and set the
    upper floor 1 mm above the 43 mm amp, which no longer fits under the U
    line.
    Centre each column's devices on its bay instead of on the piece: the
    outer columns have unequal side walls, which put everything 1.5 mm off.
    [audio-1.stl, audio-2.stl, audio-3.stl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]
2026-10-05 fix(audio-2u): centre the tab screws in the measured slots
    The slots run 30-42 mm behind the amp's face, so the screws move from
    the hedged 33 mm to the slot centre at 36 mm.
    [audio-1.stl, audio-3.stl, rack-2u-audio-stacks.scad]
2026-10-05 feat(audio-2u): add a third amp and AirPort stack to column 2
    Column 2 is now the same stack as columns 1 and 3. The blank middle
    piece stays available as part "2-blank" (stl/audio-2-blank.stl).
    [audio-2-blank.stl, audio-2.stl, rack-2u-audio-stacks.scad]
2026-10-05 feat(audio-2u): make the blank column 2 the default
    audio-2.stl is the blank middle piece again, and the third zone's stack
    moves to part "2-stack" (stl/audio-2-stack.stl) as the drop-in
    alternative.
    [audio-2-blank.stl, audio-2-stack.stl, audio-2.stl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]
2026-10-05 fix(1u): open the Pi bays for a Pi 5 with a 52Pi P30 PoE+ HAT
    The P30 stands about 30 mm on the Pi, 1 mm taller than the framed bay
    opening allowed. Run the opening out through the plate's top edge, which
    leaves 2.7 mm under the top of the 1U, and report the margin when the
    model is rendered.
    [rack-1u-hue-pi.scad, rack-1u-right.stl]
2026-10-05 docs: list the EdgeSwitch among the non-printed rack gear
2026-10-05 build: generate STLs only in release builds
    Stop tracking stl/. Pushing a v* tag now runs a workflow that exports
    every piece and attaches the STLs to a GitHub release; a manual run of
    the same workflow only builds them as an artifact.
    build.sh re-renders the committed preview images by default and exports
    STLs only with `./build.sh release`.
    [audio-1.stl, audio-2-stack.stl, audio-2.stl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]
2026-10-06 feat(audio-2u): size the amp window to the knobs, add vents, blind tab pilots
    - Amp window is 100x40 mm for the knobs, which stand 20 mm proud of the plate.
    - Add front-to-back vent slots under the amp and in the upper floor ahead of
    the AirPort.
    - Make the tab-screw pilots blind (1 mm skin) so a screw of up to tab + 5 mm
    can't exit the panel's underside; list M3x6 self-tapping screws.
    [rack-2u-audio-stacks.scad]
2026-10-06 docs(audio-2u): record the 2 mm amp tab thickness and M3x6 screw choice
2026-10-06 fix(audio-2u): seat the AirPort front-flush behind its window (#3)
    * fix(audio-2u): seat the AirPort front-flush behind its window, vent behind it
    The AirPort bay was rear-flush, leaving the AirPort 28 mm behind the front
    window. It now sits against the front plate; the exhaust slots in the upper
    floor move from ahead of the AirPort to behind it.
    * feat(audio-2u): replace the AirPort floor dimple with curved rear holders
    Two thin quarter-round walls trace the AirPort's rear corners and stop it
    sliding back; the vents behind it shift 2 mm to clear the holders' lip.
    * docs(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
    [rack-2u-audio-stacks.scad]
2026-11-01 fix(keystone): thin the latch ledge to 1.6 mm and add cutout clearance (#6)
2026-11-05 fix(keystone): open clearance to measured jack size, add fit ladder (#7)
    A measured jack body (14.53 x 16.11 mm) left ~0.1 mm a side in the 14.8 x
    16.3 mm cutout, before FDM shrink, so jacks were tight and the latch couldn't
    compress through. Cutout is now 15.1 x 16.8 mm (separate clear_w/clear_h),
    with a 0.5 mm front chamfer for elephant foot and port_t down to 1.5 mm.
    part="test" is now a 3-port ladder at -0.2/0/+0.2 mm, marked by notches.
    Claude-Session: https://claude.ai/code/session_015LRGjjPLStHXFK1m6zfzzR
2026-11-05 fix(keystone): restore 16.0 mm cutout height so the latch has an edge (#8)
    * fix(keystone): restore 16.0 mm cutout height so the latch has an edge
    The 15.1 x 16.8 mm port fit, but the latch catch sat inside the opening with
    nothing to grab. Height clearance back to 0 (standard 16.0 mm), width stays
    15.1 mm, front chamfer limited to the side edges so the bottom hook keeps its
    lip. The test ladder now varies height only: 15.8 / 16.0 / 16.2 mm.
    * docs(keystone): describe the 16.0 mm cutout height and height-only ladder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
2026-11-06 fix(keystone): thin the wall beside each port where the jack's stop ribs land (#9)
    The jack is captured between its latch catch and bottom hook (front face) and
    stop ribs on its left/right sides (back face), ~1.5 mm apart. The rear pocket
    only thinned above/below each hole, so the ribs bottomed on full 2.5 mm wall
    beside it and the catch never cleared the front face. The pocket now extends
    side_relief past each side edge; at panel pitch the pockets merge into a band.
    Height set to the 16.2 mm that fit best; the test ladder now varies port_t
    (1.3 / 1.5 / 1.7 mm).
    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
